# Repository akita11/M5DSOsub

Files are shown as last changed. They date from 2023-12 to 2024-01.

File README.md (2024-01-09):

# M5DSOsub

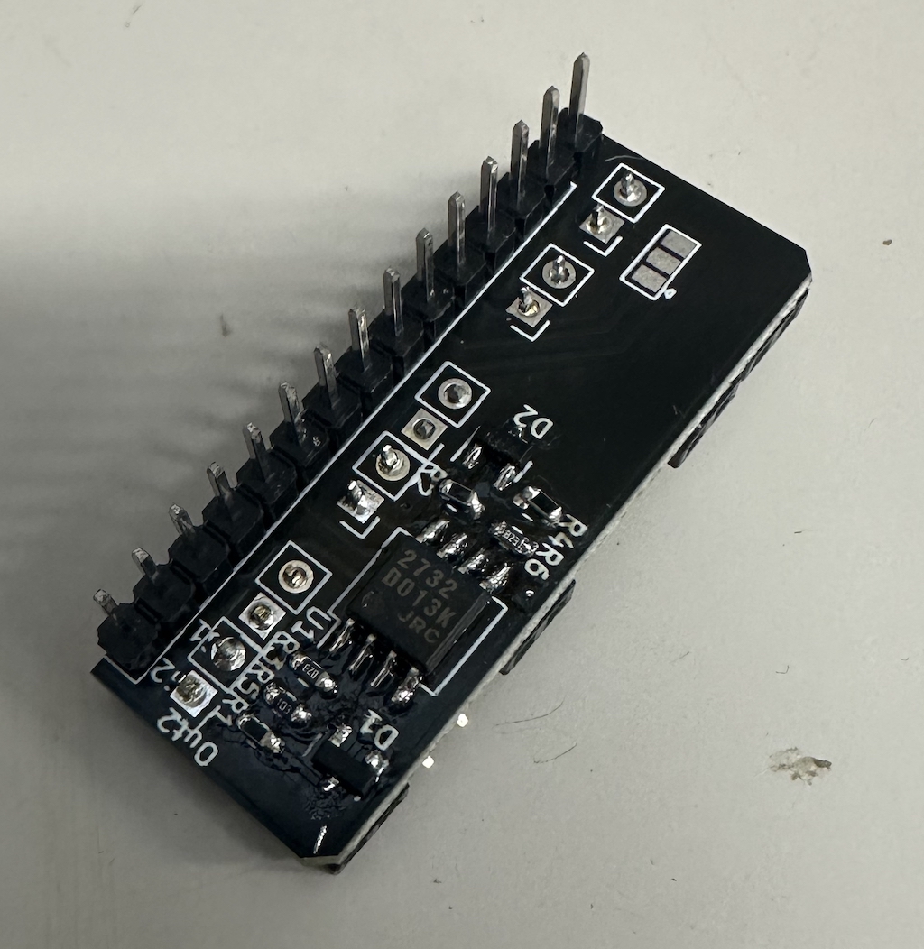
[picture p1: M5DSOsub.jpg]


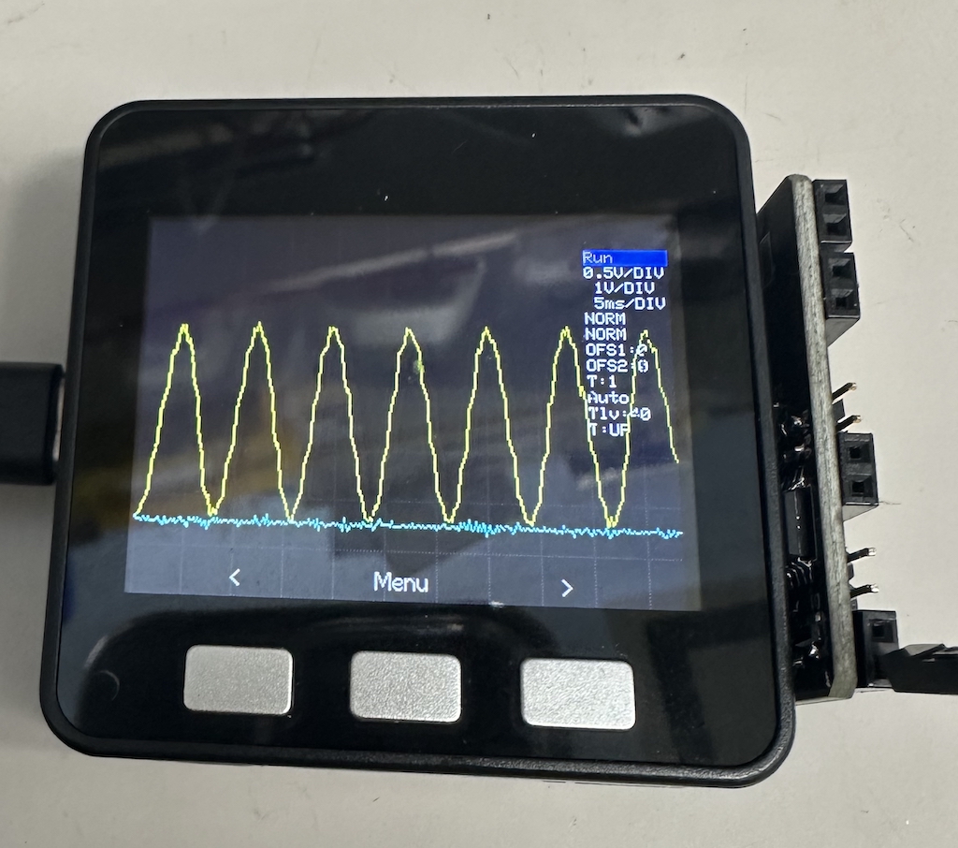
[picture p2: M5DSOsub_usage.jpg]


M5StackBasicを簡易的なオシロにするアダプタです。M5Stackを簡易オシロにするソフトウエアはいくつかあります（例えば[M5Stack-ESP32-Oscilloscope](https://github.com/botofancalin/M5Stack-ESP32-Oscilloscope)や[M5Stackオシロスコープ](https://goji2100.com/blog/?p=967)など）。いずれもM5StackのBOTTOM（底板）に出ているアナログ入力(GPIO36/35)を入力として使っています。

M5StackBasicのBOTTOMコネクタにこのアダプタを差し込むことで、これらのソフトウエアを使って、簡易オシロにすることができます。入力保護回路つきで、ショートピン切り替えで1/10アッテネータを使用できます。

※これらの2つのソフトウエアは、ArduinoIDEで使えるバージョンのESP32用ライブラリ(ESP-IDF)では再起動を繰り返す挙動があるようです。[M5Stack-ESP32-Oscilloscopeのほうは、Issueに上がっている修正](https://github.com/botofancalin/M5Stack-ESP32-Oscilloscope/issues/2)を行うことで、この問題を回避できます。

## 使い方

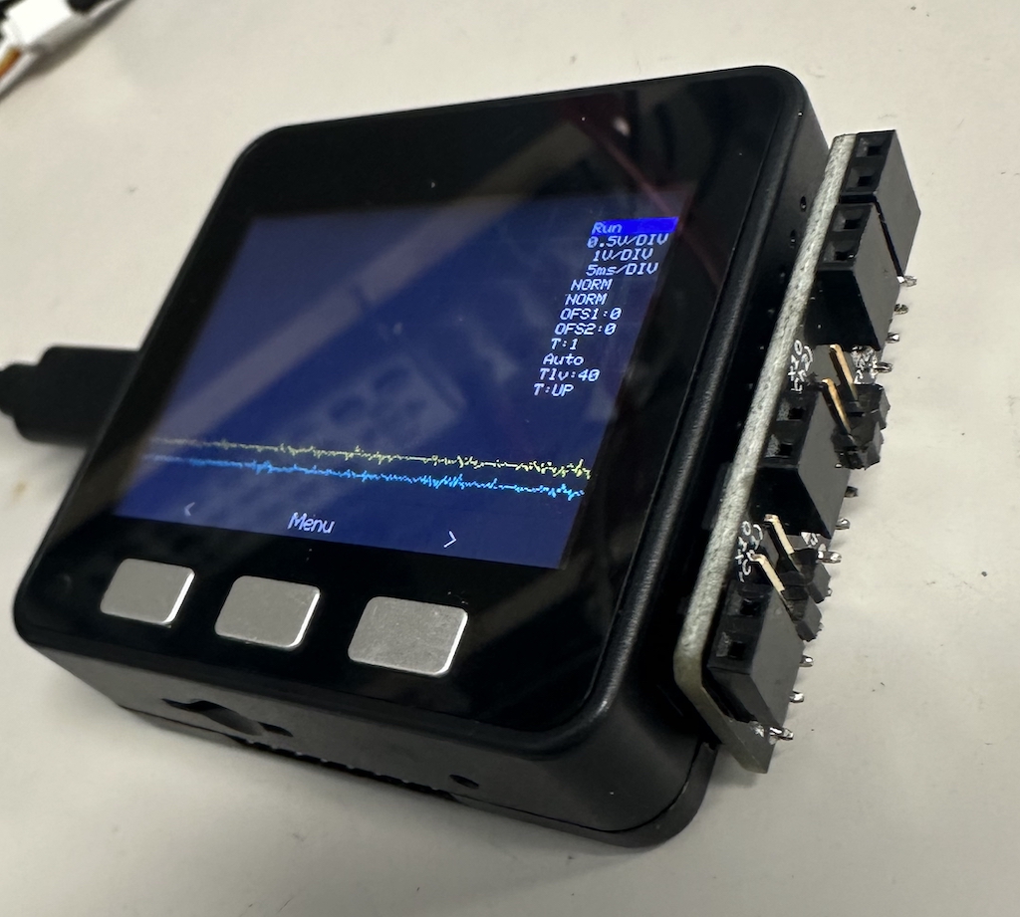
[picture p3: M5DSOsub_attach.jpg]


M5StackBasicのBOTTOMのコネクタに、このように接続します。

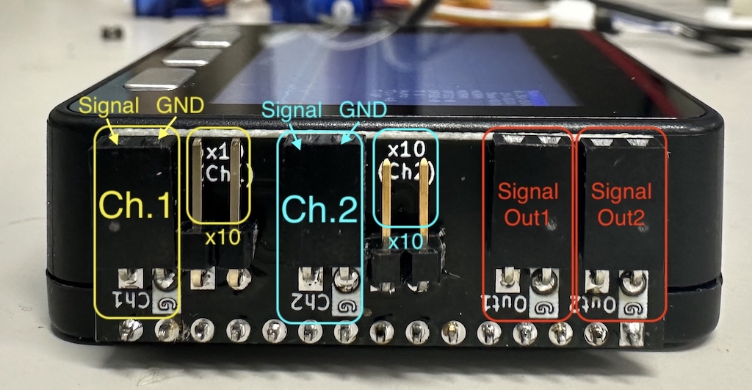
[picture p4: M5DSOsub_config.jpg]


2つのメスソケットがCh1, Ch2の入力端子（と基準電圧のGND）です。ジャンパワイヤ等で測定対象の回路に接続します。

またその横のピン（x10と表記）にショートピンをはめると、各チャンネルの入力信号が10倍に増幅されてM5Stackに与えられます。つまり1/10倍の微小な信号電圧を扱うことができます。

### パルス出力

信号チェック等に使える2つの出力波形がOut1, Out2の２つのピンソケットに出力されています。Out1はGPIO2、Out2はGPIO5（またはJP1のハンダジャンパを切り替えることでGPIO26）に接続されています。

## Author

Junichi Akita (akita@ifdl.jp, @akita11)

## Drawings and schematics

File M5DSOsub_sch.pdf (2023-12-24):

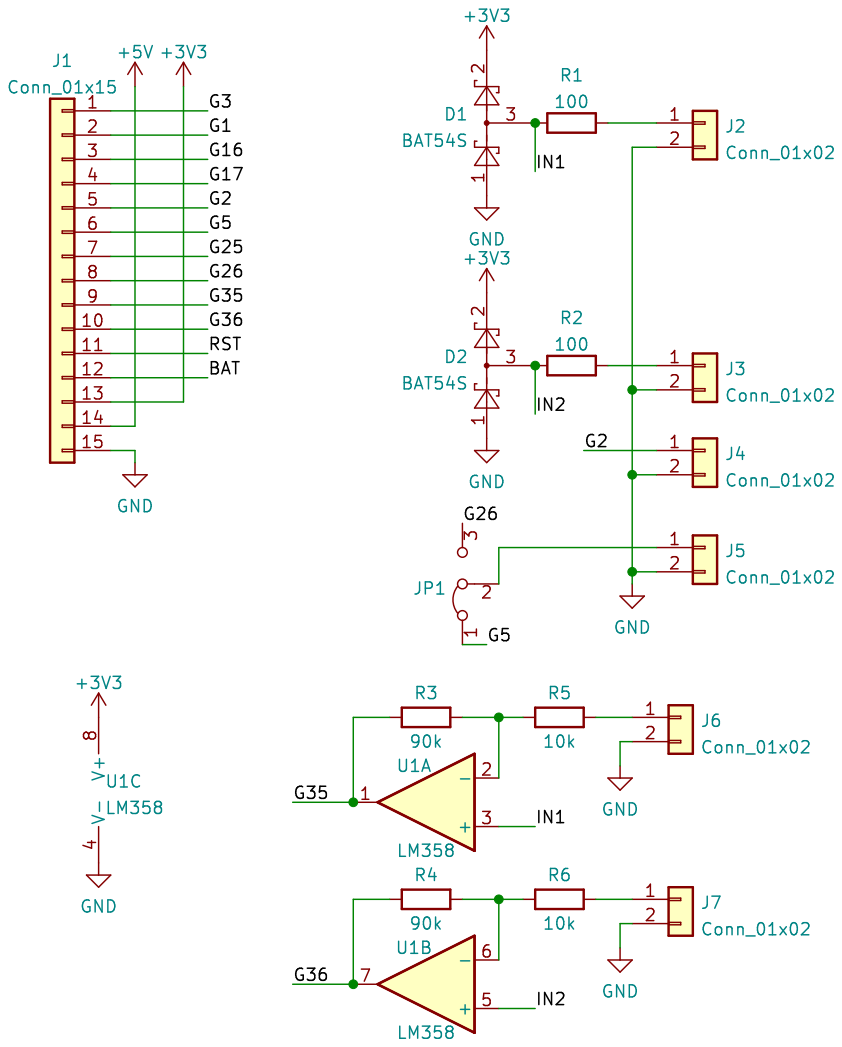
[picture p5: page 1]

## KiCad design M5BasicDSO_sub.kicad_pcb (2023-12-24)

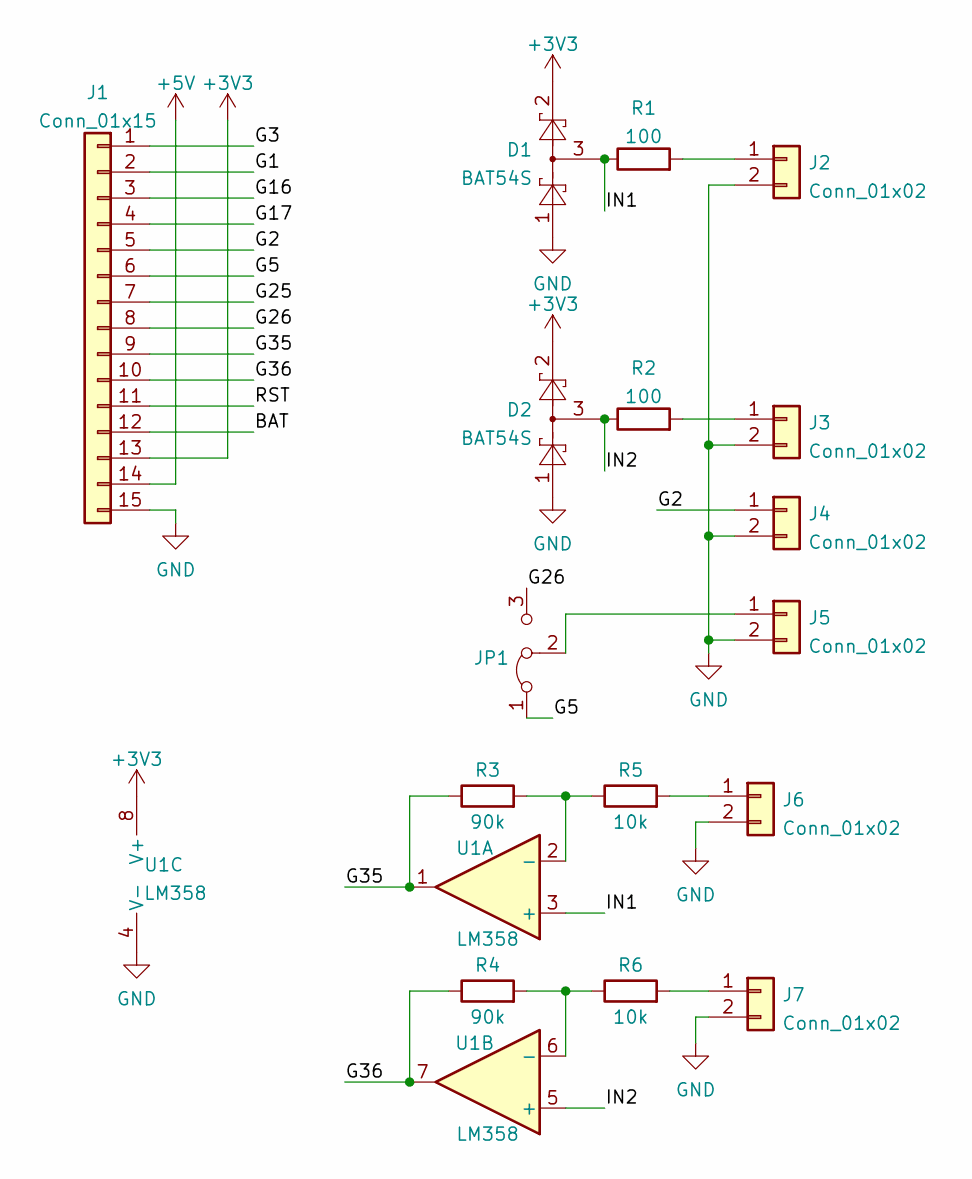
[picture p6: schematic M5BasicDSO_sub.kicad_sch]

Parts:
D1, D2: BAT54S; SOT-23
J1: Conn_01x15; PinHeader_1x15_P2.54mm_Vertical
J2, J3, J4, J5, J6, J7: Conn_01x02; PinHeader_1x02_P2.54mm_Vertical
JP1: Jumper_3_Bridged12; SolderJumper-3_P1.3mm_Bridged12_Pad1.0x1.5mm
R1, R2: 100; R_0603_1608Metric
R3, R4: 90k; R_0603_1608Metric
R5, R6: 10k; R_0603_1608Metric
U1: LM358; SO-8_5.3x6.2mm_P1.27mm

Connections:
+3V3: D1.2, D2.2, J1.13, U1.8 (V+)
+5V: J1.14
/BAT: J1.12
/G1: J1.2
/G2: J1.5, J4.1
/G3: J1.1
/G5: J1.6, JP1.1 (A)
/G16: J1.3
/G17: J1.4
/G25: J1.7
/G26: J1.8, JP1.3 (B)
/G35: J1.9, R3.1, U1.1
/G36: J1.10, R4.1, U1.7
/IN1: D1.3, R1.1, U1.3 (+)
/IN2: D2.3, R2.1, U1.5 (+)
/RST: J1.11
GND: D1.1, D2.1, J1.15, J2.2, J3.2, J4.2, J5.2, J6.2, J7.2, U1.4 (V-)
unnamed: J2.1, R1.2
unnamed: J3.1, R2.2
unnamed: J5.1, JP1.2 (C)
unnamed: J6.1, R5.2
unnamed: J7.1, R6.2
unnamed: R3.2, R5.1, U1.2 (-)
unnamed: R4.2, R6.1, U1.6 (-)

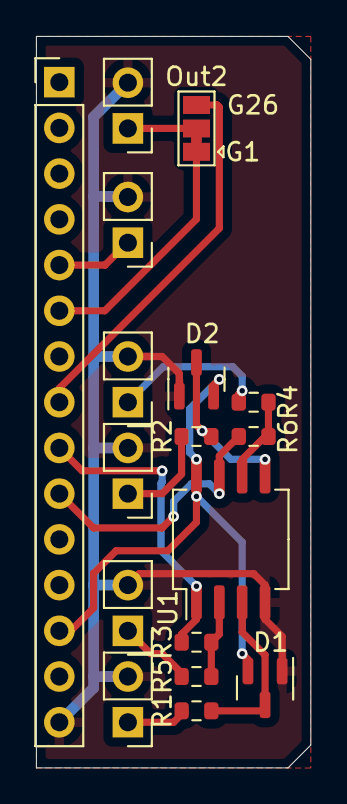
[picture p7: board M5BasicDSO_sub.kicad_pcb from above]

Board: 2 copper layers, 15.2 x 40.6 mm, 17 parts (0 on the bottom side), 16 nets.
